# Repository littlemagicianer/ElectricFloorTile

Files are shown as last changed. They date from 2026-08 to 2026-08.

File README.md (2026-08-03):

# Piezoelectric Energy-Harvesting Floor Tile

This project is a piezoelectric floor tile designed to generate electrical energy from footsteps. When a person steps on the tile, a 3D-printed PETG flexing plate transfers and distributes the force to piezoelectric elements underneath. The generated electrical signal is rectified into DC power, conditioned through an energy-harvesting circuit, and stored in a battery.

The system also measures the harvested voltage and provides the user with real-time voltage readings. The project combines mechanical design, piezoelectric energy harvesting, power electronics, PCB design, embedded sensing, and 3D printing to explore how everyday human motion can be converted into usable electrical energy.

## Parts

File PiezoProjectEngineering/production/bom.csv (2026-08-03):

Designator | Footprint | Quantity | Value | LCSC Part #
BATTERY_SCREW1, REC_SCREW1 | AMASS_XT30UPB-M_1x02_P5.0mm_Vertical | 2 | Screw_Terminal_01x02
C1 | 0603 | 1 | 1u | C696901
C11 | CP_Elec_10x10.5 | 1 | 100u | C88801
C12 | 1206 | 1 | 4.7u | C277508
C13 | 1206 | 1 | 47u | C68361
C2, C3 | 1206 | 2 | 22uF | C513771
C4, C6 | CP_Elec_10x10 | 2 | 680u | C164080
C5, C7 | CP_Elec_10x10.5 | 2 | 220u | C131159
D1 | D_SOD-323F | 1 | D_Schottky | C369937
D2, D3 | D_SMA | 2 | 1N5824 | C22452
J1, J2 | TE_1-640454-5 | 2 | Conn_01x15 | C7509525
J3, J5 | USB_C_Receptacle_GCT_USB4105-xx-A_16P_TopMnt_Horizontal | 2 | USB_C_Receptacle_USB2.0_14P | C3020560
L1 | L_Bourns_SRP7028A_7.3x6.6mm | 1 | 10u | C2041441
L2, L3 | L_Bourns_SRR1260 | 2 | 33u | C2042435
R1, R2 | 0603 | 2 | 10k | C25804
R3 | 0603 | 1 | 30k | C22984
R4 | 0805 | 1 | 40k | C5266069
R5, R6, R7, R8 | 0603 | 4 | 5.1k | C23186
U1 | MSOP-10_MSE | 1 | LTC3588IMSE-1_TRPBF | C685122
U10, U8 | SOT-23-5 | 2 | LM321 | C131103
U2 | SOT-23-5 | 1 | 74AHC1G86 | C402161
U3 | TO-220-5_P3.4x3.7mm_StaggerOdd_Lead3.8mm_Vertical | 1 | LM2596T-5 | C22386545
U6 | SOT-223-3_TabPin2 | 1 | AMS1117-3.3 | C6186
U7 | SOIC8 | 1 | FM25W256-G | C23520
U9 | TO-220-5_P3.4x3.7mm_StaggerOdd_Lead3.8mm_Vertical | 1 | LM2596T-3.3 | C1355424

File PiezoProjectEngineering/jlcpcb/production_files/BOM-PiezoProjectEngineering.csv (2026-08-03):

Comment | Designator | Footprint | LCSC | Quantity
680u | C6 | CP_Elec_10x10.5 |  | 1
D_Schottky | D1 | D_SOD-323F |  | 1
5.1k | R5 | R_0603_1608Metric |  | 1
680u | C4 | CP_Elec_10x10.5 |  | 1
33u | L2 | L_Bourns_SRR1260 |  | 1
LM2596T-3.3 | U9 | TO-220-5_P3.4x3.7mm_StaggerOdd_Lead3.8mm_Vertical |  | 1
LM321 | U8 | SOT-23-5 |  | 1
LM2596T-5 | U3 | TO-220-5_P3.4x3.7mm_StaggerOdd_Lead3.8mm_Vertical |  | 1
10k | R1 | R_0603_1608Metric |  | 1
40k | R4 | R_0603_1608Metric |  | 1
220u | C7 | CP_Elec_10x10.5 |  | 1
4.7u | C12 | C_1206_3216Metric |  | 1
Conn_01x15 | J2 | TE_1-640454-5 |  | 1
5.1k | R8 | R_0603_1608Metric |  | 1
5.1k | R7 | R_0603_1608Metric |  | 1
10u | L1 | L_Bourns_SRR1260 |  | 1
47u | C13 | C_1206_3216Metric |  | 1
22uF | C2 | C_1206_3216Metric |  | 1
74AHC1G86 | U2 | SOT-23-5 |  | 1
AMS1117-3.3 | U6 | SOT-223-3_TabPin2 |  | 1
1u | C1 | C_0603_1608Metric |  | 1
1N5824 | D2 | D_SMA |  | 1
USB_C_Receptacle_USB2.0_14P | J5 | USB_C_Receptacle_GCT_USB4105-xx-A_16P_TopMnt_Horizontal |  | 1
10k | R2 | R_0603_1608Metric |  | 1
LTC3588IMSE-1_TRPBF | U1 | MSOP-10_MSE |  | 1
USB_C_Receptacle_USB2.0_14P | J3 | USB_C_Receptacle_GCT_USB4105-xx-A_16P_TopMnt_Horizontal |  | 1
LM321 | U10 | SOT-23-5 |  | 1
1N5824 | D3 | D_SMA |  | 1
5.1k | R6 | R_0603_1608Metric |  | 1
FM25W256-G | U7 | SOIC8 |  | 1
220u | C5 | CP_Elec_10x10.5 |  | 1
22uF | C3 | C_1206_3216Metric |  | 1
100u | C11 | CP_Elec_10x10.5 |  | 1
Conn_01x15 | J1 | TE_1-640454-5 |  | 1
33u | L3 | L_Bourns_SRR1260 |  | 1
30k | R3 | R_0603_1608Metric |  | 1

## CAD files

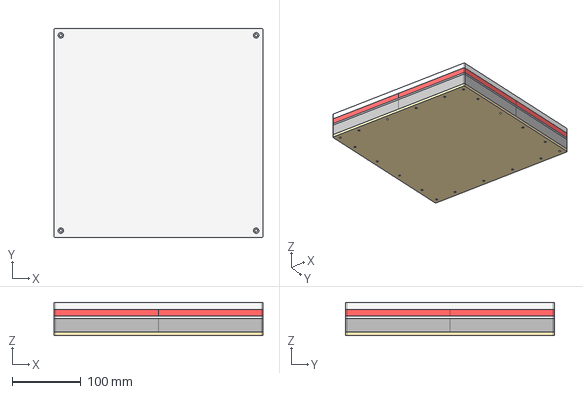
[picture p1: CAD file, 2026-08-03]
FloorTilePiezo.step
304.8 x 304.8 x 48.2 mm

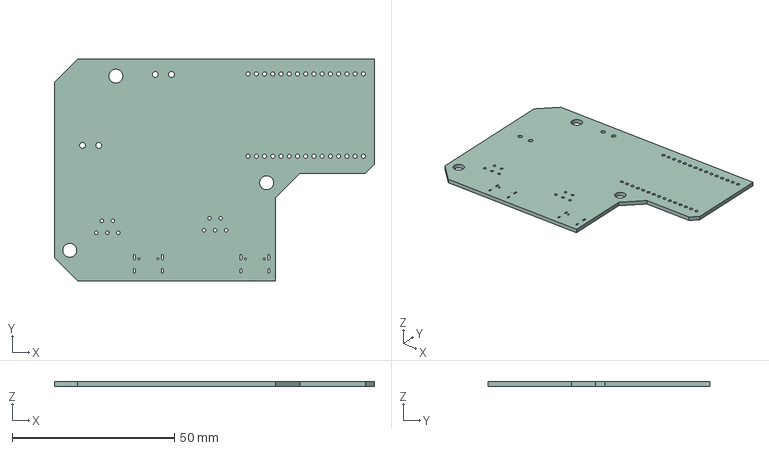
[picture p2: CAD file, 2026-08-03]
PiezoProjectEngineering/PiezoProjectEngineering.step
98.7 x 68.6 x 1.51 mm

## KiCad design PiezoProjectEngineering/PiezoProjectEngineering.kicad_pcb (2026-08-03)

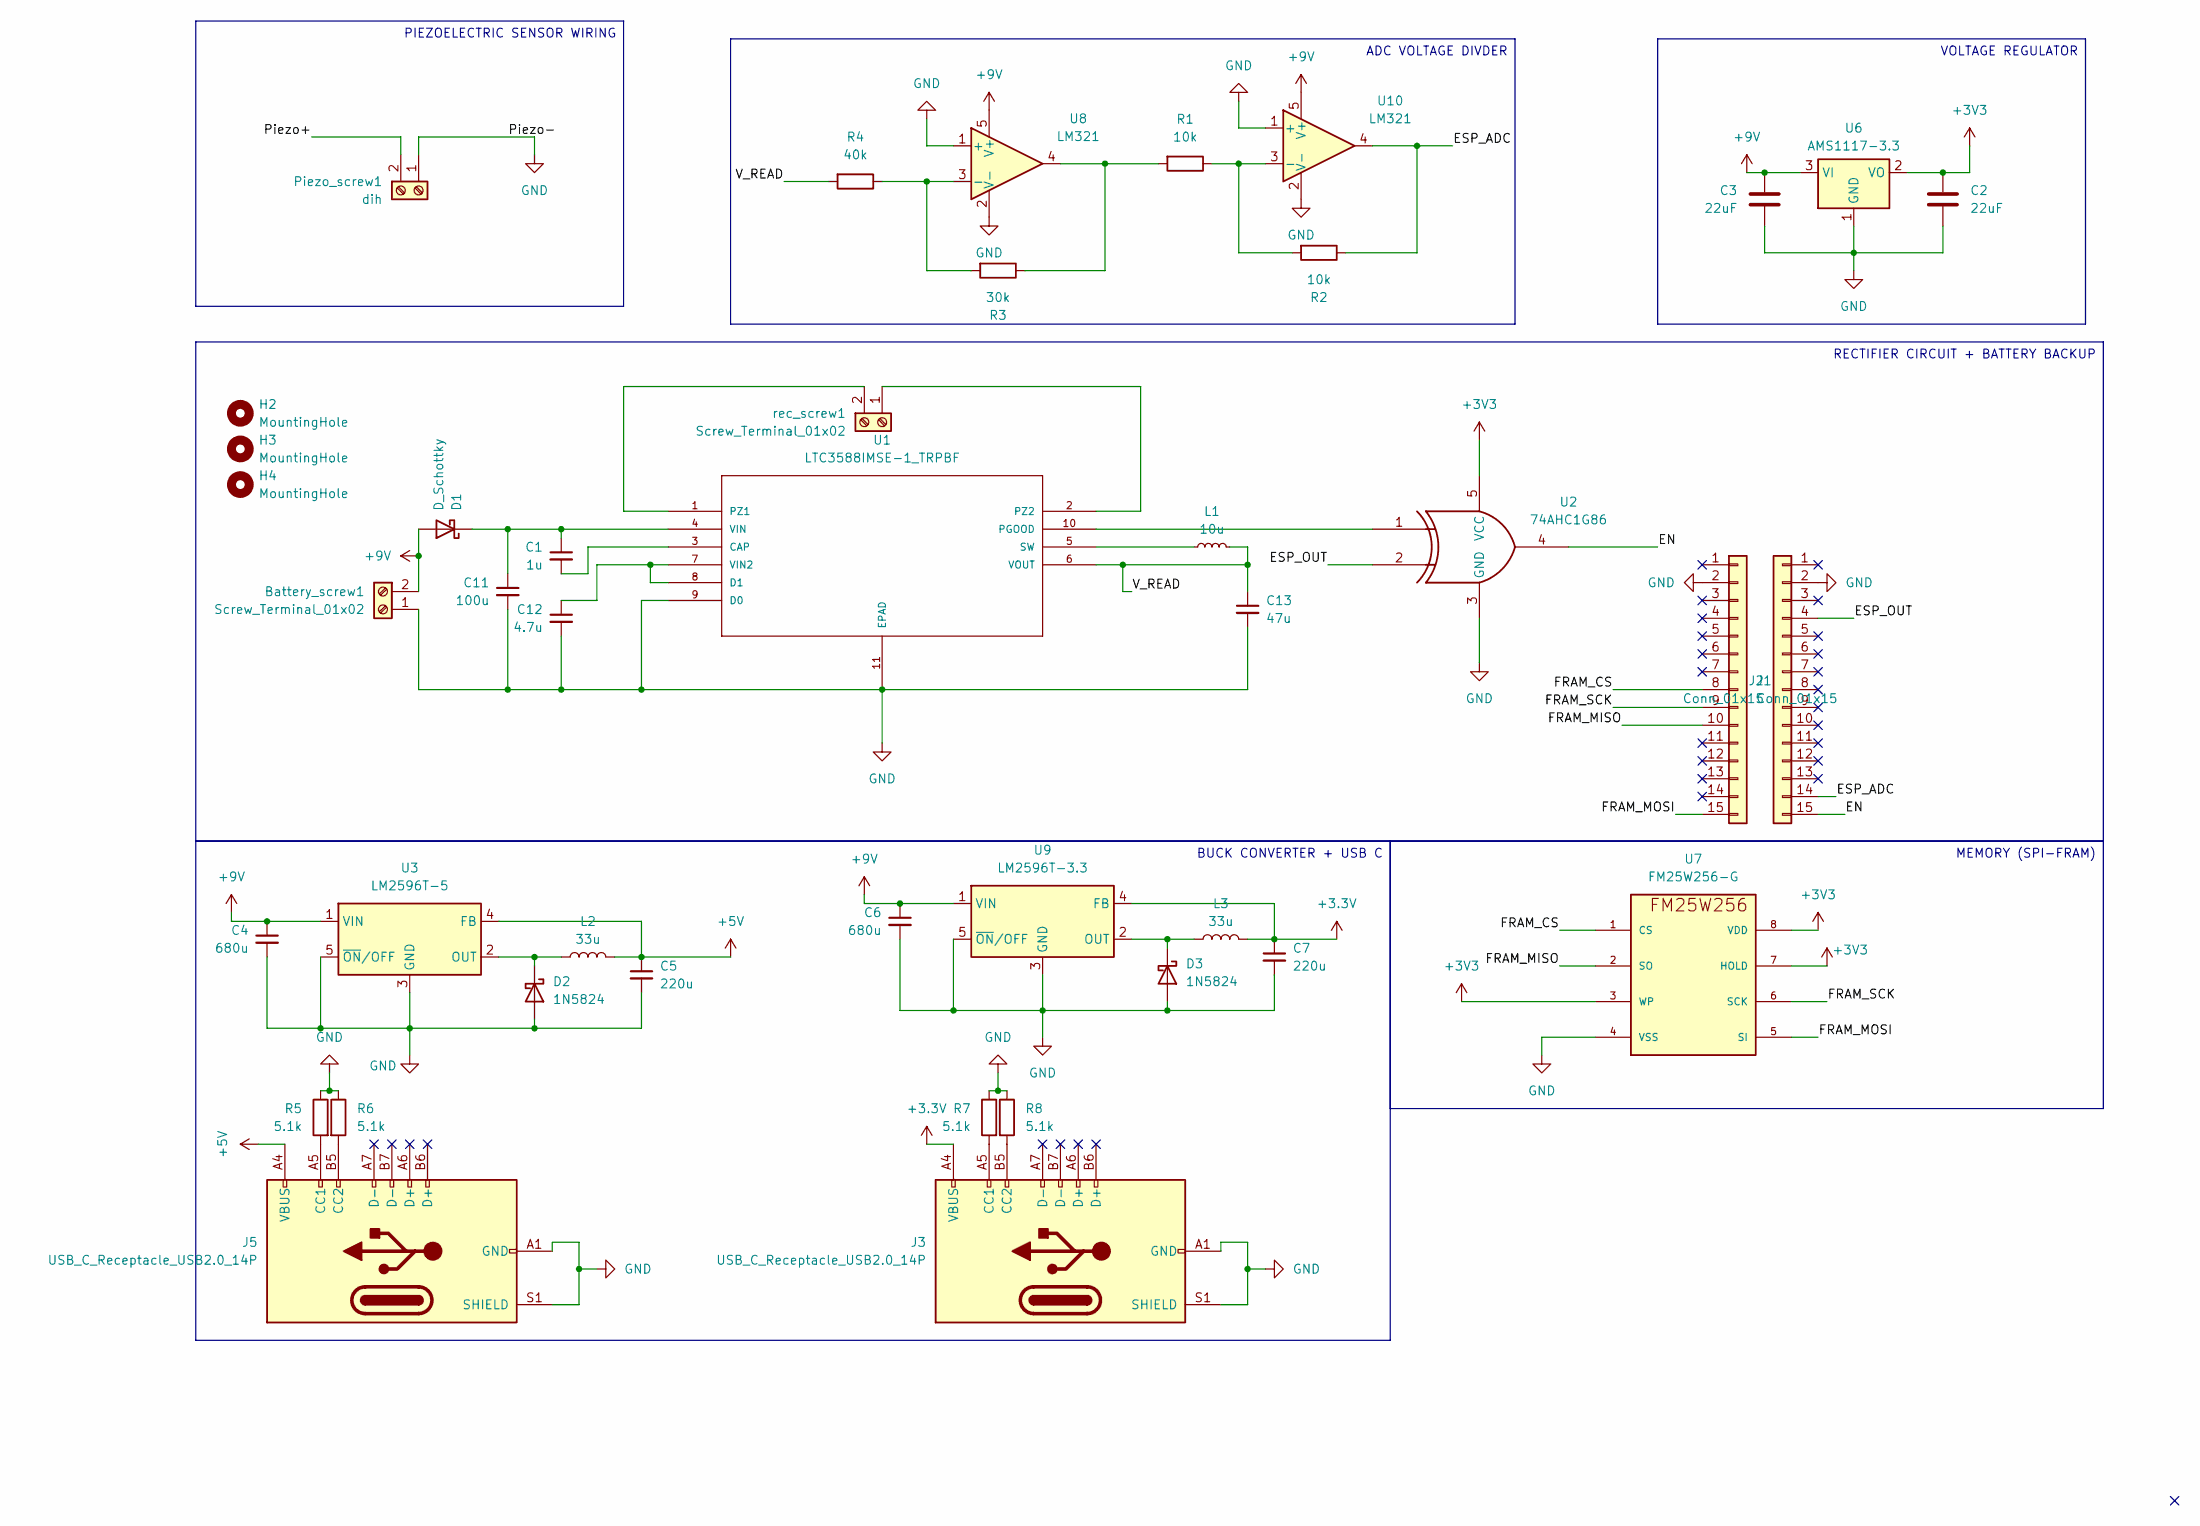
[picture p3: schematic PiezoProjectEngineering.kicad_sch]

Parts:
Battery_screw1: Screw_Terminal_01x02; AMASS_XT30UPB-M_1x02_P5.0mm_Vertical
C1: 1u; C_0603_1608Metric
C2, C3: 22uF; C_1206_3216Metric
C4, C6: 680u; CP_Elec_10x10
C5, C7: 220u; CP_Elec_10x10.5
C11: 100u; CP_Elec_10x10.5
C12: 4.7u; C_1206_3216Metric
C13: 47u; C_1206_3216Metric
D1: D_Schottky; D_SOD-323F
D2, D3: 1N5824; D_SMA
H2, H3, H4: MountingHole; MountingHole_4.3mm_M4
J1, J2: Conn_01x15; TE_1-640454-5
J3, J5: USB_C_Receptacle_USB2.0_14P; USB_C_Receptacle_GCT_USB4105-xx-A_16P_TopMnt_Horizontal
L1: 10u; L_Bourns_SRP7028A_7.3x6.6mm
L2, L3: 33u; L_Bourns_SRR1260
Piezo_screw1: dih
R1, R2: 10k; R_0603_1608Metric
R3: 30k; R_0603_1608Metric
R4: 40k; R_0805_2012Metric
R5, R6, R7, R8: 5.1k; R_0603_1608Metric
U1: LTC3588IMSE-1_TRPBF; MSOP-10_MSE; MANUFACTURER_PART_NUMBER ltc3588imse1#pbf
U2: 74AHC1G86; SOT-23-5
U3: LM2596T-5; TO-220-5_P3.4x3.7mm_StaggerOdd_Lead3.8mm_Vertical
U6: AMS1117-3.3; SOT-223-3_TabPin2
U7: FM25W256-G; SOIC8
U8, U10: LM321; SOT-23-5
U9: LM2596T-3.3; TO-220-5_P3.4x3.7mm_StaggerOdd_Lead3.8mm_Vertical
rec_screw1: Screw_Terminal_01x02; AMASS_XT30UPB-M_1x02_P5.0mm_Vertical

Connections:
+3.3V: C7.1, J3.A4 (VBUS), J3.A9 (VBUS), J3.B4 (VBUS), J3.B9 (VBUS), L3.2, U9.4 (FB)
+3V3: C2.1, U2.5 (VCC), U6.2 (VO), U7.3 (WP), U7.7 (HOLD), U7.8 (VDD)
+5V: C5.1, J5.A4 (VBUS), J5.A9 (VBUS), J5.B4 (VBUS), J5.B9 (VBUS), L2.2, U3.4 (FB)
+9V: Battery_screw1.2 (Pin_1), C3.1, C4.1, C6.1, D1.2 (A), U3.1 (VIN), U6.3 (VI), U8.5 (V+), U9.1 (VIN), U10.5 (V+)
/EN: J2.15, U2.4
/ESP_ADC: J2.14, R2.1, U10.4
/ESP_OUT: J2.4, U2.2
/FRAM_CS: J1.8, U7.1 (CS)
/FRAM_MISO: J1.10, U7.2 (SO)
/FRAM_MOSI: J1.15, U7.5 (SI)
/FRAM_SCK: J1.9, U7.6 (SCK)
/V_READ: C13.1, L1.2, R4.2, U1.6 (VOUT)
GND: Battery_screw1.1 (Pin_2), C2.2, C3.2, C4.2, C5.2, C6.2, C7.2, C11.2, C12.2, C13.2, D2.2 (A), D3.2 (A), J1.2, J2.2, J3.A1 (GND), J3.A12 (GND), J3.B1 (GND), J3.B12 (GND), J3.S1 (SHIELD), J5.A1 (GND), J5.A12 (GND), J5.B1 (GND), J5.B12 (GND), J5.S1 (SHIELD), Piezo_screw1.1 (Pin_2), R5.1, R6.1, R7.1, R8.1, U1.9 (D0), U1.11 (EPAD), U2.3 (GND), U3.3 (GND), U3.5 (~ON/OFF), U6.1 (GND), U7.4 (VSS), U8.1 (+), U8.2 (V-), U9.3 (GND), U9.5 (~ON/OFF), U10.1 (+), U10.2 (V-)
unnamed: C1.1, C11.1, D1.1 (K), U1.4 (VIN)
unnamed: D2.1 (K), L2.1, U3.2 (OUT)
unnamed: D3.1 (K), L3.1, U9.2 (OUT)
unnamed: J3.A5 (CC1), R7.2
unnamed: J3.B5 (CC2), R8.2
unnamed: J5.A5 (CC1), R5.2
unnamed: J5.B5 (CC2), R6.2
unnamed: R1.2, R3.1, U8.4
unnamed: C1.2, U1.3 (CAP)
unnamed: C12.1, U1.7 (VIN2), U1.8 (D1)
unnamed: U1.10 (PGOOD), U2.1
unnamed: U1.1 (PZ1), rec_screw1.2 (Pin_1)
unnamed: U1.2 (PZ2), rec_screw1.1 (Pin_2)
unnamed: L1.1, U1.5 (SW)
unnamed: R3.2, R4.1, U8.3 (-)
unnamed: R1.1, R2.2, U10.3 (-)

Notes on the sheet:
BUCK CONVERTER + USB C
PIEZOELECTRIC SENSOR WIRING
VOLTAGE REGULATOR
ADC VOLTAGE DIVDER
RECTIFIER CIRCUIT + BATTERY BACKUP
MEMORY (SPI-FRAM)

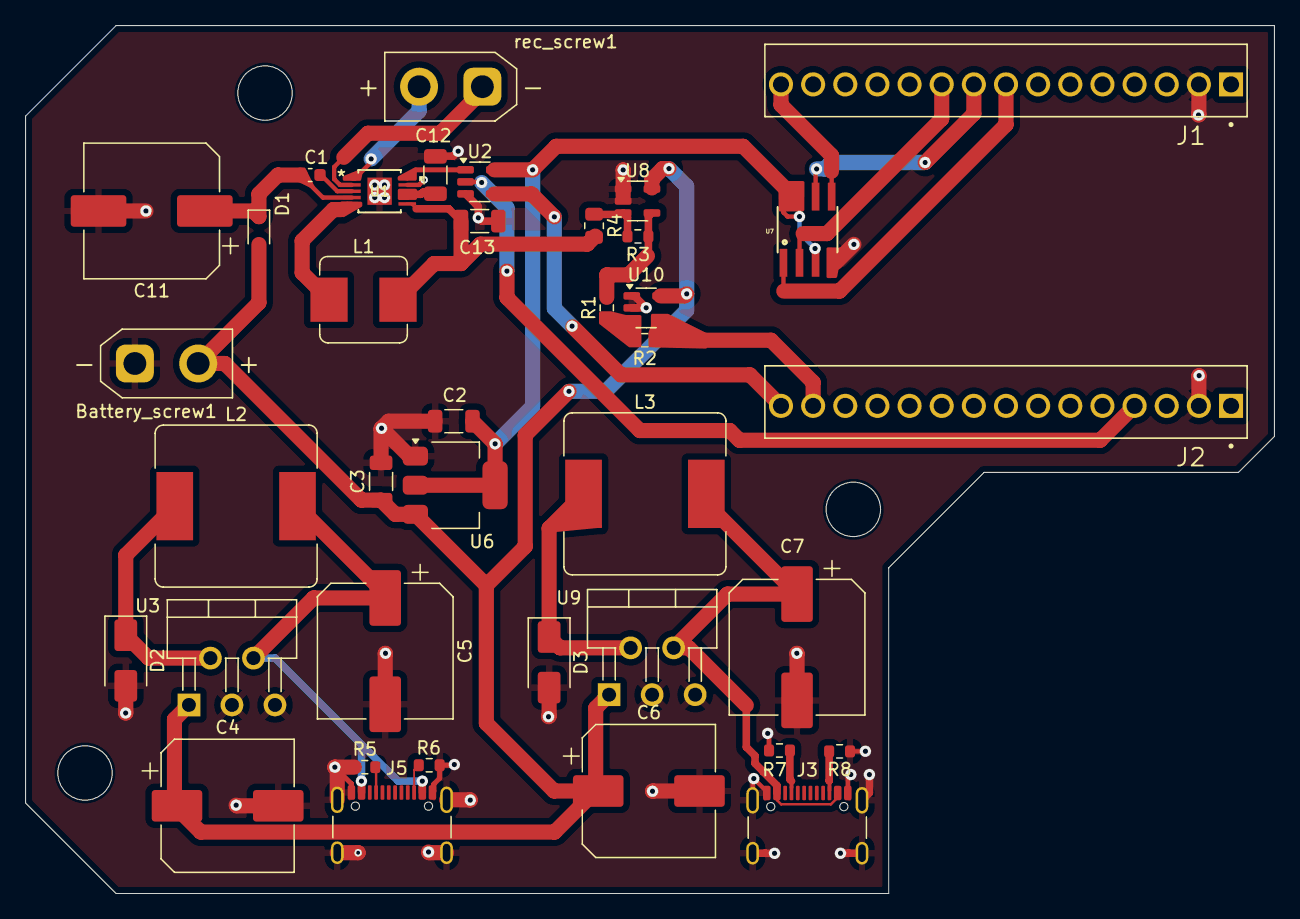
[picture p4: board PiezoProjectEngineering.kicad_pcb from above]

Board: 2 copper layers, 98.7 x 68.6 mm, 41 parts (0 on the bottom side), 29 nets.

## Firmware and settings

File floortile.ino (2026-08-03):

#include <SPI.h>

// Definitions
#define SENSOR_PIN 36   // VP Pin
#define CS_PIN     5    // Chip Select for FRAM

void setup() {
  Serial.begin(115200); // Higher speed is better for ESP32

  // Set up pins
  pinMode(CS_PIN, OUTPUT);
  digitalWrite(CS_PIN, HIGH);

  // Initialize SPI
  SPI.begin(); 

  // ESP32 ADC can be a bit jumpy; this ensures 12-bit (0-4095)
  analogReadResolution(12);

  Serial.println("System Ready. Logging VP to FRAM...");
}

void loop() {
  // 1. Read the analog value from VP
  int val = (analogRead(SENSOR_PIN));
  double volt = val*3.3/4096;
  // 2. Log to Serial Monitor so we can see it
  Serial.print("Sensor Value: ");
  Serial.println(volt);

  // 3. Write to FRAM (Simplified for this tutorial)
  // Note: We use 0x06 (WREN) and 0x02 (WRITE) commands for FM25W256
  digitalWrite(CS_PIN, LOW);
  SPI.transfer(0x06); // Write Enable
  digitalWrite(CS_PIN, HIGH);

  digitalWrite(CS_PIN, LOW);
  SPI.transfer(0x02); // Write Command
  SPI.transfer(0x00); // Address High
  SPI.transfer(0x00); // Address Low (Writing to the very beginning)
  SPI.transfer(val >> 8);   // High byte
  SPI.transfer(val & 0xFF); // Low byte
  digitalWrite(CS_PIN, HIGH);

  delay(1500); // Wait 1 seconds between logs
}

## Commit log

2026-08-03 Add files via upload
    Add ESP32 voltage sensing and SPI FRAM logging
    Reads the analog signal from the piezoelectric energy-harvesting circuit using the ESP32 ADC, converts the ADC value into an estimated voltage, and displays the reading through the Serial Monitor. Th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
2026-08-03 Add files via upload
    Add schematic, PCB layout, and JLCPCB production files
    Includes the complete circuit schematic, PCB design files, and manufacturing outputs for JLCPCB, including Gerber files, drill files, bill of materials, and component placement data.
    Schematic and PCB include a rectifier, battery backup, SPI FRAM, and ESP-32
    [BOM-PiezoProjectEngineering.csv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]
2026-08-03 Add files via upload
    Add floor tile housing, PETG flex plate, and TPU side cushions
    Includes the 3D models for the floor tile enclosure, flexible PETG top plate and tpu side cushions designed to distribute footstep pressure across the piezoelectric elements.
    [FloorTilePiezo.step]
